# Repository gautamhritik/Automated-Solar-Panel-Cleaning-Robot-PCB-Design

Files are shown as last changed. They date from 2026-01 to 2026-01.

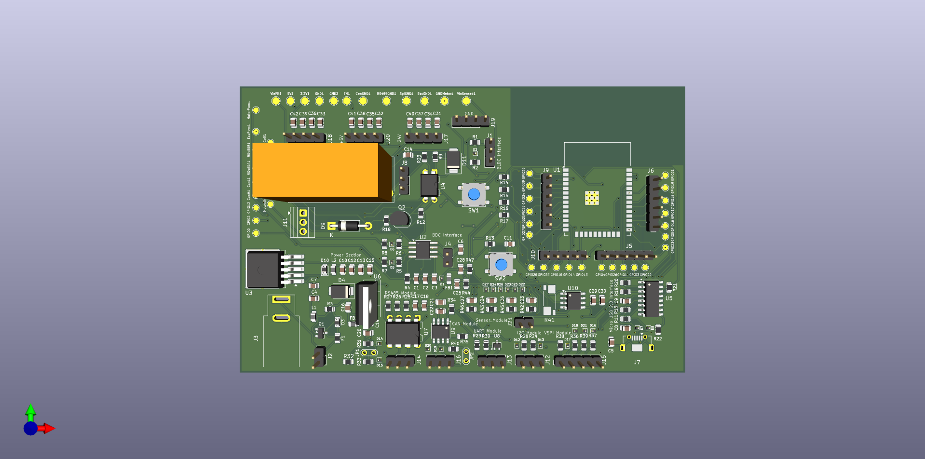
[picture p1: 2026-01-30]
Image/3D_View.png

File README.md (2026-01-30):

# Automated Solar Panel Cleaning Robot – PCB Design

## Overview
This repository contains the custom PCB design for an Automated Solar Panel Cleaning Robot.  
The PCB integrates power management, motor interfacing, sensor inputs, communication protocols and system protection required for autonomous solar panel cleaning.

This project is intended for academic, prototyping, and learning purposes.

## Key Features
- Battery-powered operation with regulated outputs
- Buck converter for 5 V and 3.3 V rails
- Motor driver interface for the cleaning mechanism
- Sensor input support (0–3.3 V range)
- Power switch and LED status indication
- Reverse polarity, overcurrent, and transient protection
- Debug and expansion headers

## PCB Specifications
- Design Tool: KiCad
- PCB Layers: 2
- Input Power: Battery / External DC supply
- Logic Levels: 3.3 V, 5 V
- Design Status: Prototype (ERC & DRC verified)
- 
## Usage
1. Open schematic and PCB files using KiCad
2. Review power paths, connectors, and component ratings
3. Modify the design if required
4. Generate Gerber files for fabrication
5. Assemble and test the PCB

## Limitations
- Prototype and academic use only
- Not weatherproof or industrially certified
- Requires enclosure for real-world deployment

## Future Improvements
- EMI and noise optimization
- Battery monitoring and protection enhancement
- Waterproof connectors and enclosure
- Firmware-based diagnostics

## License
MIT License

## Author
Hritik Gautam

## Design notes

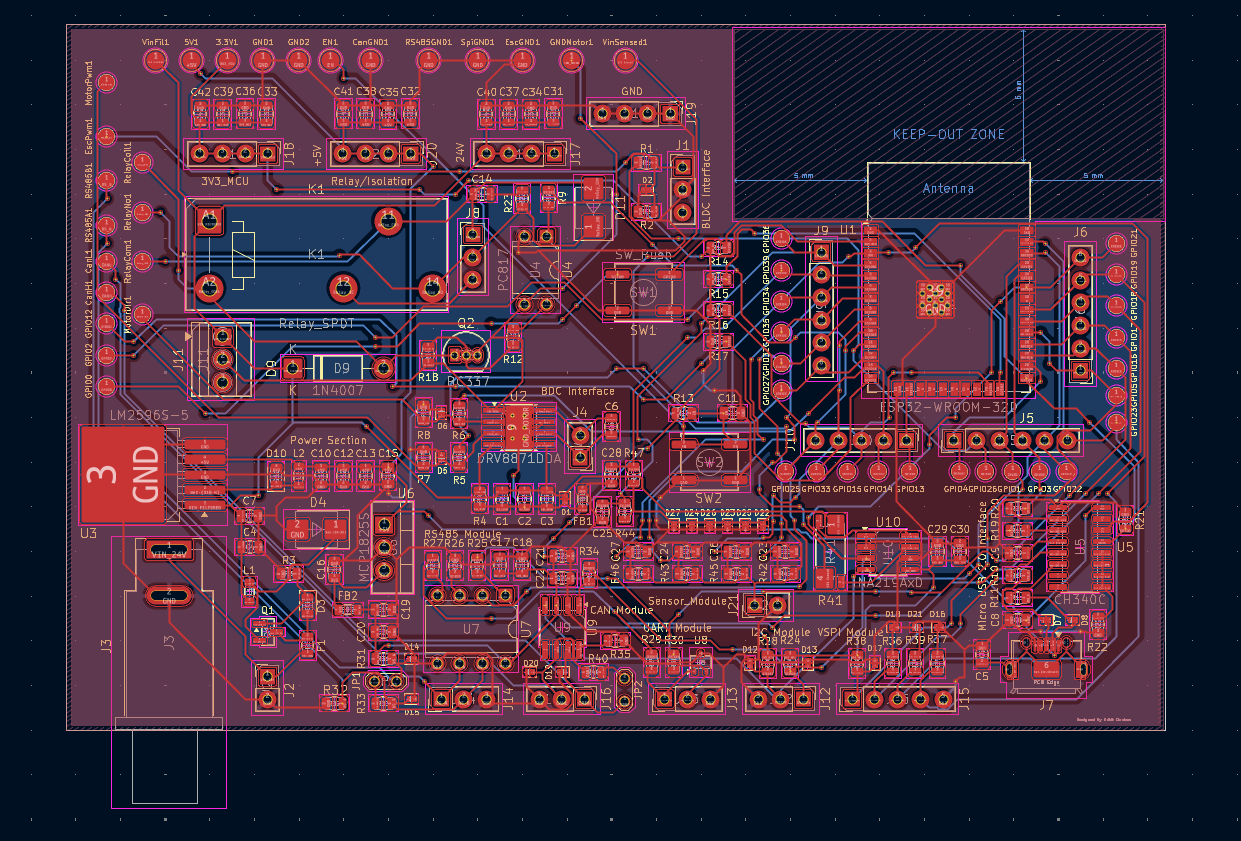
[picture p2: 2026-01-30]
Image/PCB.png

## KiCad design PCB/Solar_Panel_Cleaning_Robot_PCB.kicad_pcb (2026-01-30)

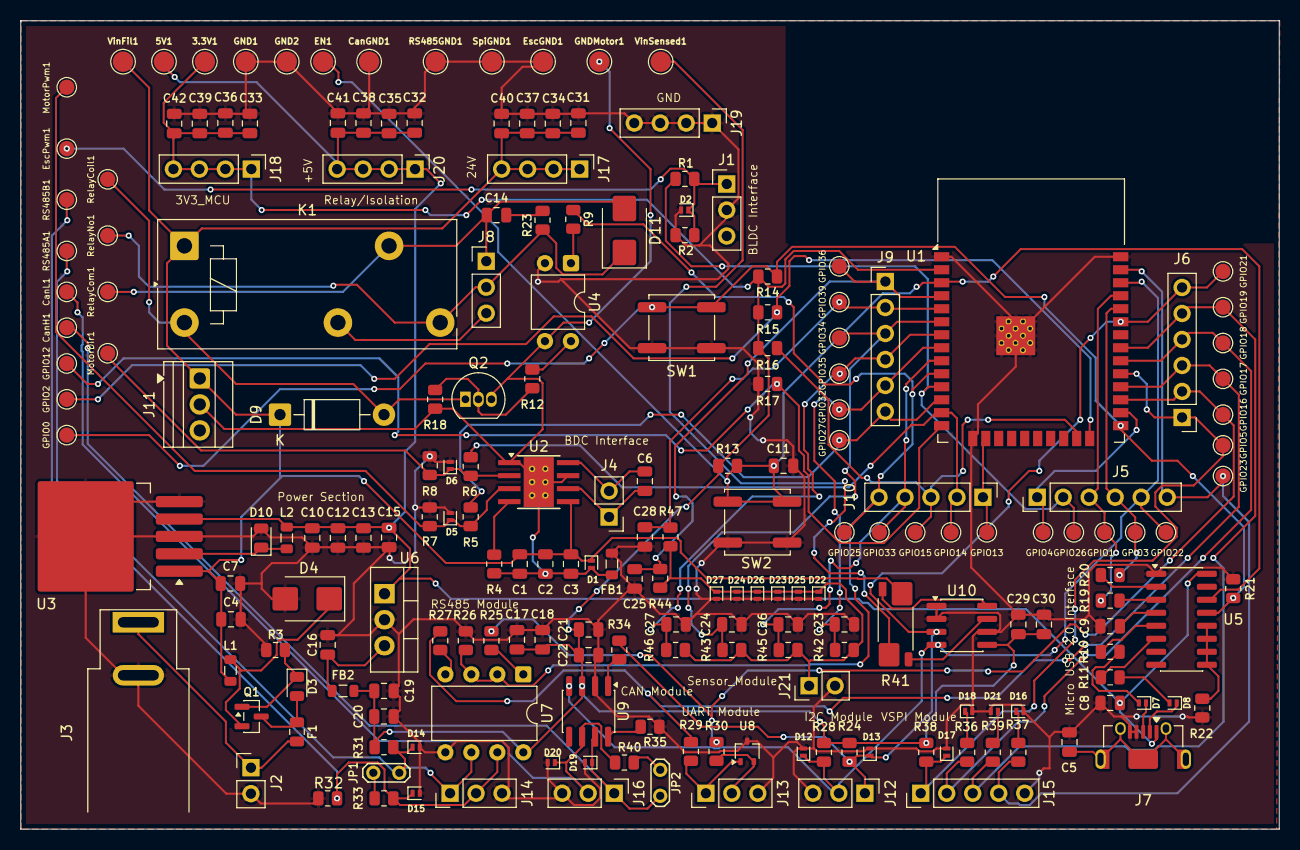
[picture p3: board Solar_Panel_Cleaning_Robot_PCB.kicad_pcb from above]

Board: 2 copper layers, 123.0 x 79.0 mm, 207 parts (0 on the bottom side), 82 nets.

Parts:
3.3V1, 5V1: TestPoint; TestPoint_Pad_D2.0mm
C1: 500µF; C_0805_2012Metric
C2, C5, C6, C9, C11, C13, C17, C20, C21, C23, C24, C25, C26, C27, C28, C29, C37, C38, C39, C40, C41, C42: 0.1µF; C_0805_2012Metric
C3, C12, C18, C19, C22, C30, C34, C35, C36: 1µF; C_0805_2012Metric
C4: C; C_0805_2012Metric
C7, C10: 100µF; C_0805_2012Metric
C8, C15, C31, C32, C33: 10µF; C_0805_2012Metric
C14: 100nF; C_0805_2012Metric
C16: 22µF; C_0805_2012Metric
CanGND1: TestPoint; TestPoint_Pad_D2.0mm
CanH1: TestPoint; TestPoint_Pad_D1.5mm
CanL1: TestPoint; TestPoint_Pad_D1.5mm
D1, D2, D5, D6, D7, D8, D12, D13, D14, D15, D16, D17, D18, D19, D20, D21, D22, D23, D24, D25, D26, D27: PESD5V0L1UL; D_SOD-882
D3: D_Zener; D_0805_2012Metric
D4, D11: D_TVS; D_SMB
D9: 1N4007; D_DO-41_SOD81_P10.16mm_Horizontal
D10: D_Schottky; D_0805_2012Metric
EN1: TestPoint; TestPoint_Pad_D2.0mm
EscGND1: TestPoint; TestPoint_Pad_D2.0mm
EscPwm1: TestPoint; TestPoint_Pad_D1.5mm
F1: Fuse; Fuse_0805_2012Metric
FB1, FB2: FerriteBead; L_0805_2012Metric
GND1, GND2: TestPoint; TestPoint_Pad_D2.0mm
GNDMotor1: TestPoint; TestPoint_Pad_D2.0mm
GPIO0, GPIO1, GPIO2, GPIO3, GPIO4, GPIO5, GPIO12, GPIO13, GPIO14, GPIO15, GPIO16, GPIO17, GPIO18, GPIO19, GPIO21, GPIO22, GPIO23, GPIO25, GPIO26, GPIO27, GPIO32, GPIO33, GPIO34, GPIO35, GPIO36, GPIO39: TestPoint; TestPoint_Pad_D1.5mm
J1, J8, J12, J13, J14, J16: Conn_01x03_Pin; PinHeader_1x03_P2.54mm_Vertical
J2, J4, J21: Conn_01x02_Pin; PinHeader_1x02_P2.54mm_Vertical
J3: Jack-DC; BarrelJack_SwitchcraftConxall_RAPC10U_Horizontal
J5, J6, J9: Conn_01x06_Pin; PinHeader_1x06_P2.54mm_Vertical
J7: USB_B_Micro; USB_Micro-AB_Molex_47590-0001
J10, J15: Conn_01x05_Pin; PinHeader_1x05_P2.54mm_Vertical
J11: Screw_Terminal_01x03; TerminalBlock_Xinya_XY308-2.54-3P_1x03_P2.54mm_Horizontal
J17, J18, J19, J20: Conn_01x04_Pin; PinHeader_1x04_P2.54mm_Vertical
JP1, JP2: Jumper_2_Open; TestPoint_2Pads_Pitch2.54mm_Drill0.8mm
K1: Relay_SPDT; Relay_SPDT_Finder_40.51
L1: L; L_0805_2012Metric
L2: 47µH; L_0805_2012Metric
MotorDir1: TestPoint; TestPoint_Pad_D1.5mm
MotorPwm1: TestPoint; TestPoint_Pad_D1.5mm
Q1: Q_PMOS_GDS; SOT-23
Q2: BC337; TO-92_Inline
R1, R5, R6, R19, R20, R23: 100; R_0805_2012Metric
R2, R7, R8: 100K; R_0805_2012Metric
R3, R13, R14, R15, R16, R17, R18, R21, R22, R26, R35: 10K; R_0805_2012Metric
R4: 22K; R_0805_2012Metric
R9, R31, R32: 680; R_0805_2012Metric
R10, R11: 22; R_0805_2012Metric
R12, R42, R43, R44, R45, R46, R47: 1K; R_0805_2012Metric
R24, R28: 4.7K; R_0805_2012Metric
R25, R27, R29, R30, R34: 33; R_0805_2012Metric
R33, R40: 120; R_0805_2012Metric
R36, R37, R39: 47; R_0805_2012Metric
R38: 47K; R_0805_2012Metric
R41: R_Shunt = 5 mΩ, ≥2 W, 2512package; R_Shunt_Vishay_WSK2512_6332Metric_T1.19mm
RS485A1, RS485B1: TestPoint; TestPoint_Pad_D1.5mm
RS485GND1: TestPoint; TestPoint_Pad_D2.0mm
RelayCoil1: TestPoint; TestPoint_Pad_D1.5mm
RelayCom1: TestPoint; TestPoint_Pad_D1.5mm
RelayNo1: TestPoint; TestPoint_Pad_D1.5mm
SW1, SW2: SW_Push; SW_Push_1P1T_NO_CK_KSC7xxJ
SpiGND1: TestPoint; TestPoint_Pad_D2.0mm
U1: ESP32-WROOM-32D
U2: DRV8871DDA; Texas_HTSOP-8-1EP_3.9x4.9mm_P1.27mm_EP2.95x4.9mm_Mask2.4x3.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
U3: LM2596S-5; TO-263-5_TabPin3
U4: PC817; DIP-4_W7.62mm
U5: CH340C; SOIC-16_3.9x9.9mm_P1.27mm
U6: MCP1825S; TO-220-3_Vertical
U7: MAX3485; DIP-8_W7.62mm
U8: TPD2E2U06DCK; SOT-323_SC-70
U9: SN65HVD230; SOIC-8_3.9x4.9mm_P1.27mm
U10: INA219AxD; SOIC-8_3.9x4.9mm_P1.27mm
VinFil1: TestPoint; TestPoint_Pad_D2.0mm
VinSensed1: TestPoint; TestPoint_Pad_D2.0mm

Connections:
/3V3: C16.1, FB2.1, U6.3 (VO)
/3V3_MCU: 3.3V1.1, C17.1, C18.1, C19.1, C20.1, C21.1, C22.1, C29.1, C30.1, C33.1, C36.1, C39.1, C42.1, FB2.2, J18.1, J18.2, J18.3, J18.4, R13.1, R14.2, R15.2, R16.2, R24.1, R28.1, R31.2, R38.2, U1.2 (VDD), U7.8 (VCC), U9.3 (VCC), U10.5 (VS)
/+5V: 5V1.1, C8.1, C10.1, C12.1, C13.1, C15.1, C32.1, C35.1, C38.1, C41.1, J7.1 (VBUS), J20.1, J20.2, J20.3, J20.4, L2.2, U3.4 (FB), U5.16 (VCC), U6.1 (VI)
/CANH: CanH1.1, D19.1 (K), J16.1, JP2.1 (A), U9.7 (CANH)
/CANL: CanL1.1, D20.1 (K), J16.2, R40.1, U9.6 (CANL)
/EN: C11.1, EN1.1, R13.2, SW2.2, U1.3 (EN), U5.14 (~RTS)
/ESC_PWM_OUT: D2.1 (K), EscPwm1.1, J1.1, R1.2, R2.2
/GND_MOTOR: C1.2, C2.2, C3.2, D1.2 (A), FB1.1, GNDMotor1.1, J11.2, Q2.3 (E), R4.1, R18.1, U2.1 (GND), U2.7 (GND), U2.9 (GND), U4.3
/GPIO0: GPIO0.1, R14.1, R21.2, SW1.1, U1.25 (IO0), U5.13 (~DTR)
/GPIO1: GPIO1.1, J5.3, R19.1, U1.35 (TXD0/IO1)
/GPIO2: GPIO2.1, R15.1, U1.24 (IO2)
/GPIO3: GPIO3.1, J5.4, R20.2, U1.34 (RXD0/IO3)
/GPIO4/RS: GPIO4.1, J5.1, U1.26 (IO4)
/GPIO12: GPIO12.1, R17.1, U1.14 (IO12)
/GPIO13: GPIO13.1, J10.1, U1.16 (IO13)
/GPIO14: GPIO14.1, J10.2, R6.1, U1.13 (IO14)
/GPIO15: GPIO15.1, J10.3, R16.1, U1.23 (IO15)
/GPIO16: GPIO16.1, J6.2, R25.1, R30.2, U1.27 (IO16)
/GPIO17: GPIO17.1, J6.3, R27.1, R29.2, U1.28 (IO17)
/GPIO21: D13.1 (K), GPIO21.1, J6.6, J12.1, R24.2, R34.1, U1.33 (IO21), U10.3 (SDA)
/GPIO22: D12.1 (K), GPIO22.1, J5.5, J12.2, R28.2, U1.36 (IO22), U9.4 (R), U10.4 (SCL)
/GPIO25: GPIO25.1, J10.5, R9.1, R26.2, U1.10 (IO25), U7.2 (~RE), U7.3 (DE)
/GPIO26: GPIO26.1, J5.2, R1.1, U1.11 (IO26)
/GPIO27: GPIO27.1, J9.6, R5.1, U1.12 (IO27)
/GPIO32: C23.1, GPIO32.1, J9.5, R42.1, U1.8 (IO32)
/GPIO33: C26.1, GPIO33.1, J10.4, R45.1, U1.9 (IO33)
/GPIO34: C24.1, GPIO34.1, J9.3, R43.1, U1.6 (IO34)
/GPIO35: C27.1, GPIO35.1, J9.4, R46.1, U1.7 (IO35)
/GPIO36: C25.1, GPIO36.1, J9.1, R44.1, U1.4 (SENSOR_VP)
/GPIO39: C28.1, GPIO39.1, J9.2, R47.1, U1.5 (SENSOR_VN)
/J_Motor Pin 1: C6.2, J4.1, U2.6 (OUT1)
/J_Motor Pin 2: C6.1, J4.2, U2.8 (OUT2)
/MOTOR_DIR: D6.1 (K), MotorDir1.1, R6.2, R8.2, U2.2 (IN2)
/MOTOR_PWM: D5.1 (K), MotorPwm1.1, R5.2, R7.2, U2.3 (IN1)
/RS_A: D14.1 (K), J14.1, JP1.1 (A), R31.1, RS485A1.1, U7.6 (A)
/RS_B: D15.1 (K), J14.2, R32.1, R33.1, RS485B1.1, U7.7 (B)
/Relay_COIL: D9.2 (A), K1.A2, Q2.1 (C), RelayCoil1.1
/Relay_COM: C14.1, D11.2 (A2), J8.1, K1.11, RelayCom1.1
/Relay_NC: J8.3, K1.12
/Relay_NO: D11.1 (A1), J8.2, K1.14, R23.1, RelayNo1.1
/Sensor_Out: D22.1 (K), D23.1 (K), D24.1 (K), D25.1 (K), D26.1 (K), D27.1 (K), J21.1, R42.2, R43.2, R44.2, R45.2, R46.2, R47.2
/USB_D+: D7.2 (A), R10.1
/USB_D-: D8.2 (A), R11.1
/VIN_24V: F1.1, J2.1, J3.1
/VIN_FILTERED: C1.1, C2.1, C3.1, C4.1, C7.1, C31.1, C34.1, C37.1, C40.1, D1.1 (K), D9.1 (K), J11.1, J17.1, J17.2, J17.3, J17.4, K1.A1, L1.2, R41.1, U2.5 (VM), U3.1 (VIN), VinFil1.1
/VIN_Sensed: R41.4, VinSensed1.1
/VSPI_GPIO5_CS: D17.1 (K), GPIO5.1, J6.1, J15.1, R38.1, U1.29 (IO5)
/VSPI_GPIO18_SCLK: GPIO18.1, J6.4, J15.2, R36.1, U1.30 (IO18)
/VSPI_GPIO19_MISO: GPIO19.1, J6.5, J15.3, R39.1, U1.31 (IO19)
/VSPI_GPIO23_MOSI: GPIO23.1, J5.6, J15.4, R37.1, U1.37 (IO23)
GND: C4.2, C5.1, C7.2, C8.2, C9.2, C10.2, C11.2, C12.2, C13.2, C15.2, C16.2, C17.2, C18.2, C19.2, C20.2, C21.2, C22.2, C23.2, C24.2, C25.2, C26.2, C27.2, C28.2, C29.2, C30.2, C31.2, C32.2, C33.2, C34.2, C35.2, C36.2, C37.2, C38.2, C39.2, C40.2, C41.2, C42.2, CanGND1.1, D2.2 (A), D4.2 (A2), D5.2 (A), D6.2 (A), D10.2 (A), D12.2 (A), D13.2 (A), D14.2 (A), D15.2 (A), D16.2 (A), D17.2 (A), D18.2 (A), D19.2 (A), D20.2 (A), D21.2 (A), D22.2 (A), D23.2 (A), D24.2 (A), D25.2 (A), D26.2 (A), D27.2 (A), EscGND1.1, FB1.2, GND1.1, GND2.1, J1.2, J2.2, J3.2, J7.4 (ID), J7.5 (GND), J12.3, J13.3, J14.3, J15.5, J16.3, J19.1, J19.2, J19.3, J19.4, J21.2, R2.1, R3.2, R7.1, R8.1, R17.2, R21.1, R22.1, R26.1, R32.2, R35.1, RS485GND1.1, SW1.2, SW2.1, SpiGND1.1, U1.1 (GND), U1.15 (GND), U1.38 (GND), U1.39 (GND), U3.3 (GND), U3.5 (~ON/OFF), U4.2, U5.1 (GND), U6.2 (GND), U7.5 (GND), U8.3, U9.2 (GND), U10.1 (A1), U10.2 (A0), U10.6 (GND)
unnamed: C14.2, R23.2
unnamed: D3.2 (A), F1.2, Q1.3 (S)
unnamed: D3.1 (K), Q1.1 (G), R3.1
unnamed: D4.1 (A1), L1.1, Q1.2 (D)
unnamed: D7.1 (K), J7.3 (D+)
unnamed: D8.1 (K), J7.2 (D-)
unnamed: D10.1 (K), L2.1, U3.2 (OUT)
unnamed: D16.1 (K), R37.2
unnamed: D18.1 (K), R36.2
unnamed: D21.1 (K), R39.2
unnamed: C5.2, J7.6 (Shield)
unnamed: J13.1, R29.1, U8.1
unnamed: J13.2, R30.1, U8.2
unnamed: JP1.2 (B), R33.2
unnamed: JP2.2 (B), R40.2
unnamed: Q2.2 (B), R12.2, R18.2
unnamed: R9.2, U4.1
unnamed: R12.1, U4.4
unnamed: R4.2, U2.4 (ILIM)
unnamed: R19.2, U5.3 (RXD)
unnamed: R20.1, U5.2 (TXD)
unnamed: R10.2, U5.5 (UD+)
unnamed: R11.2, U5.6 (UD-)
unnamed: C9.1, U5.4 (V3)
unnamed: R22.2, U5.9 (~CTS), U5.10 (~DSR), U5.11 (~RI), U5.12 (~DCD)
unnamed: R27.2, U7.4 (DI)
unnamed: R25.2, U7.1 (RO)
unnamed: R34.2, U9.1 (D)
unnamed: R35.2, U9.8 (Rs)
unnamed: R41.2, U10.8 (IN+)
unnamed: R41.3, U10.7 (IN-)

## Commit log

2026-01-30 Second Commit
    [Solar_Panel_Cleaning_Robot_PCB.kicad_sch]
2026-01-30 Add README for Automated Solar Panel Cleaning Robot
    Added detailed documentation for the Automated Solar Panel Cleaning Robot PCB design, including features, specifications, usage instructions, limitations, and future improvements.
